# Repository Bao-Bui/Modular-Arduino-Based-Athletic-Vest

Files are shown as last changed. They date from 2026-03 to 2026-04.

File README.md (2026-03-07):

# Modular-Arduino-Based-Athletic-Vest

This fitness vest offers essential tracking—heart rate, steps, speed, and real-time goal feedback—combined with post-workout data storage via a local microSD card. Unlike traditional wearables, its open-enclosure design allows users to customize the device by adding Arduino-compatible sensors for advanced, personalized metrics.

### Materials:

* **Enclosed space (V5):** battery/top/bottom pieces; two side holes for nuts/bolts securing
* **Nuts and bolts (for enclosure fastening):** M3 x7, M4 x2
* **Haimont 10L running Vest**
* **Arduino + PCB “motherboard” assembly:** (PCB preserves Arduino pins through female headers)
* **SparkFun GPS module:** Chip Antenna, SAM-M10Q (Qwiic)
* **SparkFun OpenLog module:** (Qwiic)
* **MicroSD card:** (recommended: SanDisk 32GB Ultra, FAT32, 32GB)
* **MicroSD USB card reader**
* **MPU6050 Gyroscope/IMU**
* **JST cable harness:** (2.54 mm JST + 2.0 mm JST LCD end)
* **Qwiic wires**
* **ST7789 LCD screen:** + wrist case with Velcro
* **Power bank:** (INIU P41L-E2 class, 45W, 10,000 mAh)
* **Polar H10 chest strap + sensor:** (battery pre-installed)









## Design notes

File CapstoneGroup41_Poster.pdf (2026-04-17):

# Modular Athletic Vest

# Bao Bui, Oliver Escobar, Alexander Perez, Esei Haile Grand Canyon University

## Project Justification

- Most fitness wearables (Garmin, Fitbit, WHOOP) operate in closed ecosystems
- Users can only connect a limited set of approved sensors
- Advanced metrics (muscle activation, force, custom biomechanics) are not supported

## Project Description

The Modular Athletic Vest is an Arduino-based wearable designed to provide standard fitness tracking:
- Heart rate monitoring
- Step counting
- Speed tracking
- Real-time exercise feedback based on user goals
- Workout data storage on a microSD card

Unlike traditional wearables, the vest has a modular architecture, allowing users to integrate additional Arduino-compatible sensors to measure advanced physiological or biomechanical metrics.

Target Users
- Coaches analyzing athlete performance
- Competitive athletes needing advanced training metrics
- Tech-savvy fitness enthusiasts interested in custom hardware

## Design Process

The PCB layout includes connections for the Arduino R4, MPU6050 IMU, GPS module, OpenLog SD storage, and LCD interface. The design incorporates standardized mounting holes, optimized trace routing, and JST connectors for reliable communication and power distribution across the system (Fig. 1).

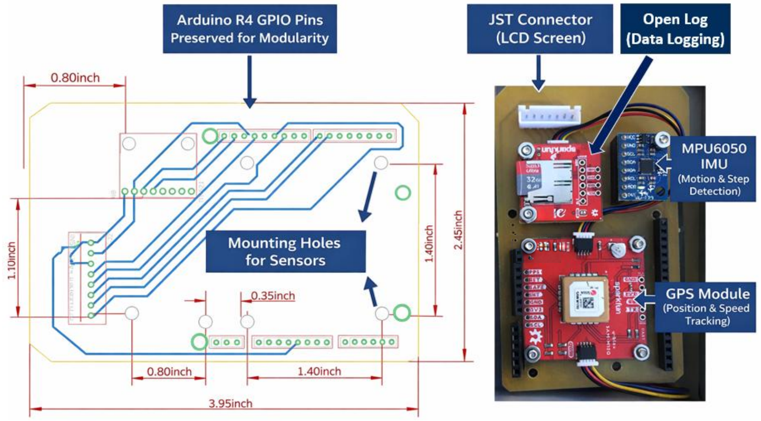
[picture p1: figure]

Figure 1. Custom PCB layout for an integrated sensor and microcontroller system.

System workflow from setup to output includes initialization, sensor integration, and data processing. Real-time inputs (heart rate, steps, and speed) are filtered and processed before being displayed on the LCD and stored for later analysis (Fig. 2).

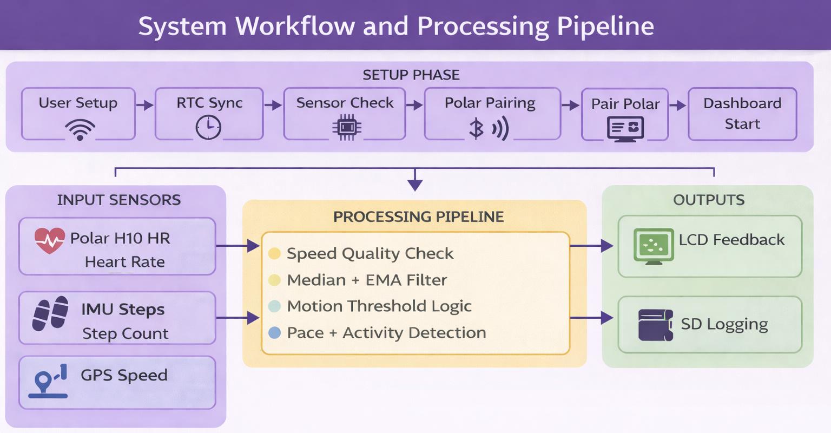
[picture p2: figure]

Figure 2. System workflow and real-time processing pipeline for the modular athletic vest.

A three-part enclosure houses the Arduino-PCB system and battery. The vest shows enclosure integration into the lower compartment with wiring for the LCD interface that was Velcro-mounted on a wrist case (Fig. 3).

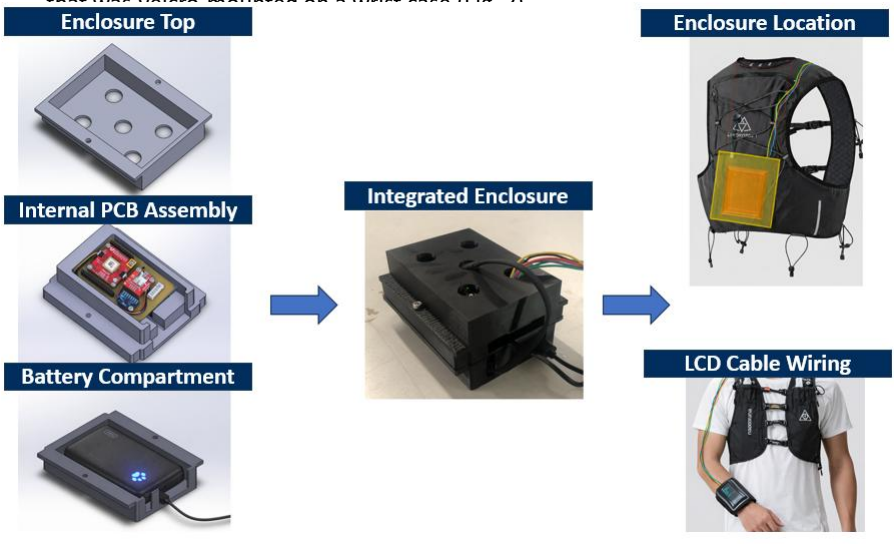
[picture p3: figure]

Figure 3. Enclosure design and integration into the wearable vest system.

## System Performance & Validation

The functional requirements assessment confirms that the modular athletic vest meets all key performance criteria, including accuracy in heart rate (100% specificity), step tracking (MAPE = 4.69%), speed tracking (MAPE = 8.86%), battery life, data storage, and enclosure design. Validation was guided by established standards such as IEC 62133-2:2017, IEC 60601-2-47:2012, ISO 924-210:2019, and ISO 12100, with additional benchmarking methods used where formal standards
were not available. Functional Requirement | Product Specification | Engineering Standards/ Alternative Tests | Result (Pass/Fail)
Long battery life | Runtime > 24 hours | IEC 62133-2:2017 | FAIL (23.5 hours)
Accurate heart rate detection | Specificity > 91% | IEC 60601-2-47:2012 | PASS (100%)
Accurate step tracking | MAPE < 20% (Mora-Gonzalez et al., 2022) | Manual step count comparison | PASS (4.69%)
Accurate speed tracking | MAPE < 10% (Alphin et al., 2020) | Radar gun comparison | PASS (8.86%)
Effective user feedback system | Rating ≥ 7/10 | ISO 9241-210:2019 | PASS (8.69)
User comfort | Rating ≥ 7/10 | ISO 9241-210:2019 | PASS (7.82)
Reliable data storage | Success rate ≥ 90% | Functional storage test | PASS (100%)
Modular enclosure | ≥ 2 holes ≥ 15 mm | Dimensional measurement | PASS
Secure enclosure locking | No failure under use | ISO 12100 | PASS
Sweat/water resistance | Hermeticity testing | IEC 60529 ISO 105-E04 | PENDING

## References

- International Electrotechnical Commission. (2017). Secondary cells and batteries containing alkaline or other non-acid electrolytes – Safety requirements for portable sealed secondary cells, and for batteries made from them, for use in portable applications – Part 2: Lithium systems (IEC 62133-2:2017).
- International Electrotechnical Commission. (2012). Medical electrical equipment—Part 2-47: Particular requirements for the basic safety and essential performance of ambulatory electrocardiographic systems (IEC 60601-2-47:2012).
- International Organization for Standardization. (2019). Ergonomics of human-system interaction—Part 210: Human-centred design for interactive systems (ISO 9241-210:2019).
- International Organization for Standardization. (2010). Safety of machinery—General principles for design—Risk assessment and risk reduction (ISO 12100).
- Alphin, K. L., Sisson, O. M., Hudgins, B. L., Noonan, C. D., & Bunn, J. A. (2020). Accuracy assessment of a GPS device for maximum sprint speed. International Journal of Exercise Science, 13(4), 273–280.
- Mora-Gonzalez, J., Gould, Z. R., Moore, C. C., Aguiar, E. J., Ducharme, S. W., Schuna, J. M., Barreira, T. V., Staudenmayer, J., McAvoy, C. R., Boikova, M., Miller, T. A., & Tudor-Locke, C. (2022). A catalog of validity indices for step counting wearable technologies during treadmill walking: The CADENCE-adults study. International Journal of Behavioral Nutrition and Physical Activity, 19(1), 117. https://doi.org/10.1186/s12966-022-01350-9

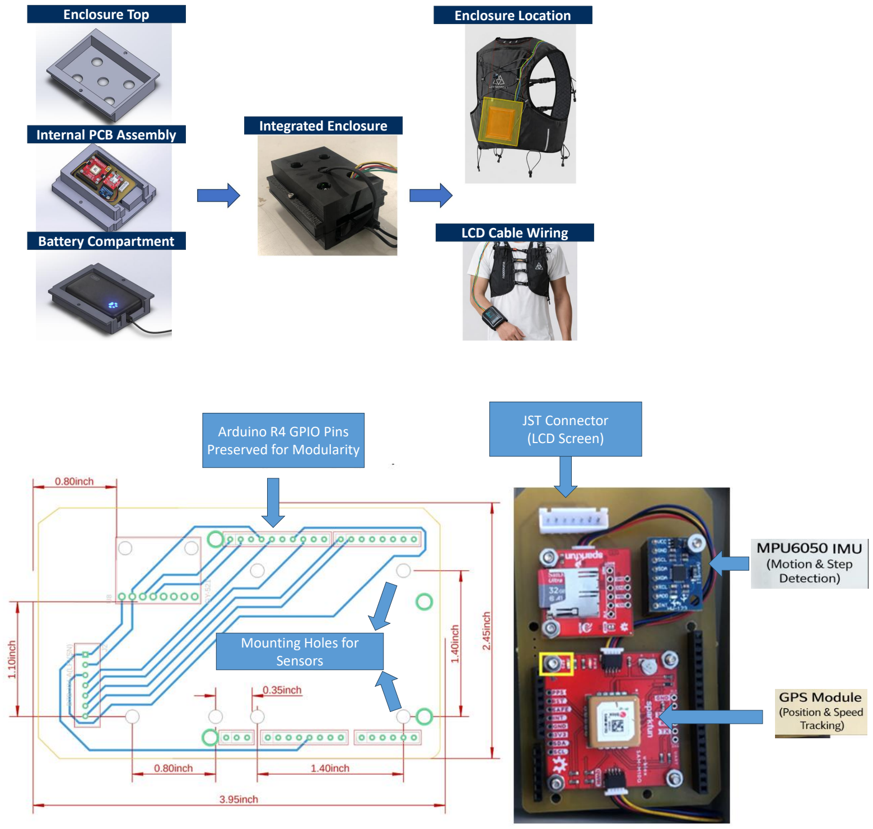
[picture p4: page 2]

JST Connector
(LCD Screen) Arduino R4 GPIO Pins Preserved for Modularity

Mounting Holes for
Sensors

Enclosure Top

Internal PCB Assembly

Battery Compartment

Integrated Enclosure

Enclosure Location

LCD Cable Wiring

Functional Requirement | Product Specification | Engineering Standards/ Alternative Tests | Result (Pass/Fail)
Long battery life | Runtime > 24 hours | IEC 62133-2:2017 | FAIL (23.5 hours)
Accurate heart rate detection | Specificity > 91% | IEC 60601-2-47:2012 | PASS (100%)
Accurate step tracking | MAPE < 20% (Mora-Gonzalez et al., 2022) | Manual step count comparison | PASS (4.69%)
Accurate speed tracking | MAPE < 10% (Alphin et al., 2020) | Radar gun comparison | PASS (8.86%)
Effective user feedback system | Rating ≥ 7/10 | ISO 9241-210:2019 | PASS (8.69)
User comfort | Rating ≥ 7/10 | ISO 9241-210:2019 | PASS (7.82)
Reliable data storage | Success rate ≥ 90% | Functional storage test | PASS (100%)
Modular enclosure | ≥ 2 holes ≥ 15 mm | Dimensional measurement | PASS
Secure enclosure locking | No failure under use | ISO 12100 | PASS
Sweat/water resistance | Hermeticity testing | IEC 60529 ISO 105-E04 | PENDING

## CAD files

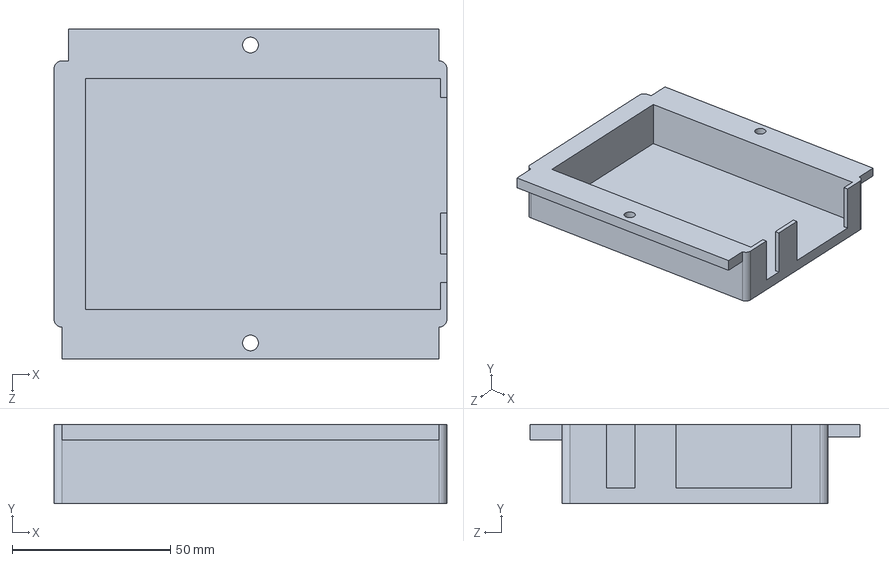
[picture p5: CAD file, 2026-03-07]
ArduinoEnclosureBattery_V2.SLDPRT
124.0 x 25.0 x 104.0 mm

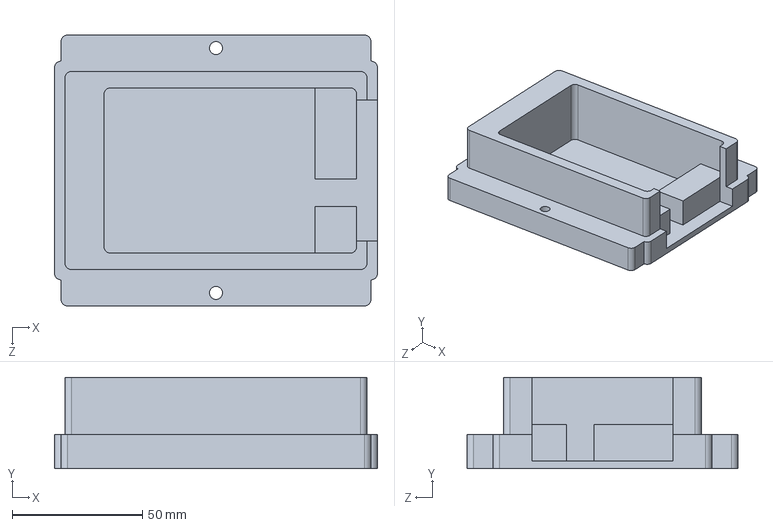
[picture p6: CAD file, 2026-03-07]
ArduinoEnclosureBottom_V2.SLDPRT
124.0 x 35.0 x 104.0 mm

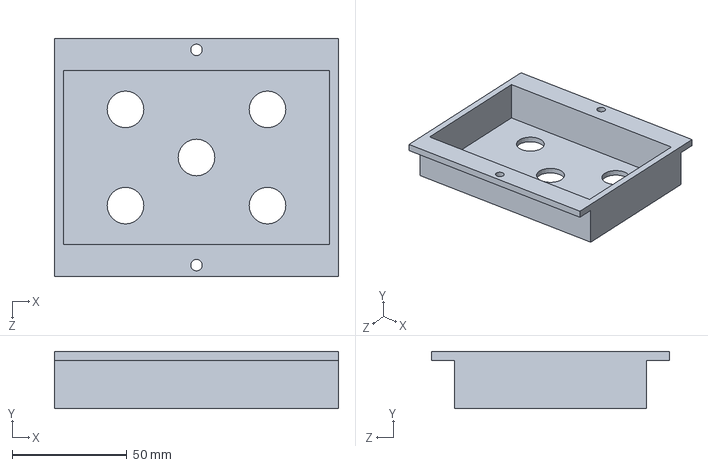
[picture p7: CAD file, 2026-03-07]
ArduinoEnclosureTop_V2.SLDPRT
124.0 x 25.0 x 104.0 mm

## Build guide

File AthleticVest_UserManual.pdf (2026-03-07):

# Arduino-Based Modular Athletic Vest

## User Manual & Research Guide

Prototype V5
Capstone Group 41, College of Engineering

Date: March 6, 2026

Table of Contents

## Contents

### 1. Intended Purpose and Use Limitations

The Arduino-Based Modular Athletic Vest is a wearable fitness-tracking system designed to record workout data such as heart rate, speed/pace (outdoor GPS), step count, and breathing estimates. It is intended for personal fitness training, experimentation, and Arduino-based sensor integration.

This device is not intended for medical purposes. It does not diagnose, treat, monitor, or prevent any disease or medical condition. All outputs should be treated as fitness-level estimates, not clinical measurements.

Use limitations and environment:
- Not rain/IP-rated: Do not use in rain, showers, or wet environments. The enclosure and electronics are not waterproof or IP-certified.
- Indoor use is limited: GPS typically will not lock indoors without a clear view of the sky, so speed/pace may be unavailable indoors.
- Normal sweat is acceptable. Wipe down after use.
- Avoid extreme temperatures. Storage/operation above 85°C is not recommended.

### 2. What’s Included (Package Contents)

Your kit includes the following components:
- Enclosed space (V5): battery/top/bottom pieces; two side holes for nuts/bolts securing
- Nuts and bolts (for enclosure fastening)
- M3 x7
- M4 x2
- Haimont 10L running Vest
- Arduino + PCB “motherboard” assembly (PCB preserves Arduino pins through female headers)
- SparkFun GPS module - Chip Antenna, SAM-M10Q (Qwiic)
- SparkFun OpenLog module (Qwiic)
- MicroSD card (recommended: SanDisk 32GB Ultra, FAT32, 32GB)
- MicroSD USB card reader
- MPU6050 Gyroscope/IMU
- JST cable harness (2.54 mm JST + 2.0 mm JST LCD end)
- Qwiic wires
- ST7789 LCD screen + wrist case with Velcro
- Power bank (INIU P41L-E2 class, 45W, 10,000 mAh)
- Polar H10 chest strap + sensor (battery pre-installed)

What the user must provide:
- Smartphone (for Vest_Setup Wi-Fi configuration)
- Laptop/computer (for viewing CSV files)

### 3. Device Description (How the System Works)

The vest system consists of a wearable platform (vest + wrist display) connected to a modular electronics enclosure that houses the Arduino and sensor/logging hardware. The vest records data during exercise and logs it to a microSD card as a CSV file for post-workout analysis. The system is intentionally modular so users can remove the Arduino/PCB assembly and attach additional Arduino-compatible sensors using available interfaces.

Major subsystems:
- Electronics enclosure: Holds Arduino + PCB, power connection, and sensor modules.
- Wrist display: LCD shows workout information and status.
- Sensor suite: GPS (outdoor speed/pace), IMU for steps/motion, Polar chest strap for HR and breathing estimate.
- Data logging: OpenLog + microSD stores workout CSV files for analysis.

### 4. Safety Information

4.1 Electrical and handling safety
This is an electronics-based fitness device. Use common electrical safety precautions. If anything smells hot, shuts off unexpectedly, or becomes unusually warm, immediately power down (unplug the power bank).
- Do not expose electronics to water (no rain, no submersion, no wet cleaning while electronics are installed).
- Do not operate with cracked housings, damaged insulation, or loose wiring.
- Do not modify wiring while the device is powered.

4.2 Environmental safety

- Not IP-rated: Do not use in rain or wet environments.
- Avoid dust-heavy or sandy environments that can contaminate connectors.
- Avoid extreme heat; do not leave in a hot vehicle.

4.3 Personal safety

- Route cables to avoid snagging during running.
- Wear the Polar chest strap comfortably; discontinue use if irritation occurs.
- If you have an implanted electronic device (e.g., pacemaker), use caution with wearable electronics and consult a professional if uncertain.

### 5. Setup and Assembly

5.1 Cable routing (if cable was removed)
The cable is usually already routed through the vest and wrist case. If it is removed accidentally, reroute it as follows:

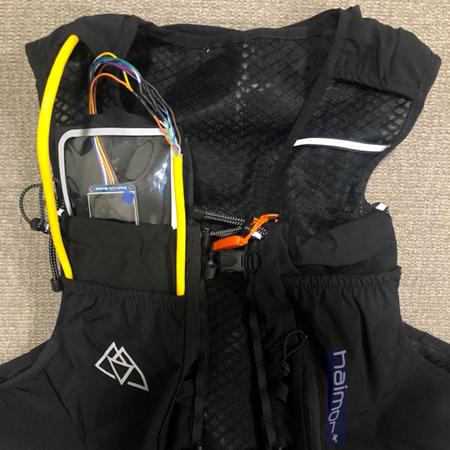
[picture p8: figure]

Figure 4. Cable routing through vest compartments (example layout).

1. Route the 2.54 mm JST end through the hole between the water compartment (largest compartment) and bottom compartment.
2. Route the 2.0 mm LCD JST end through the hole on the right shoulder.

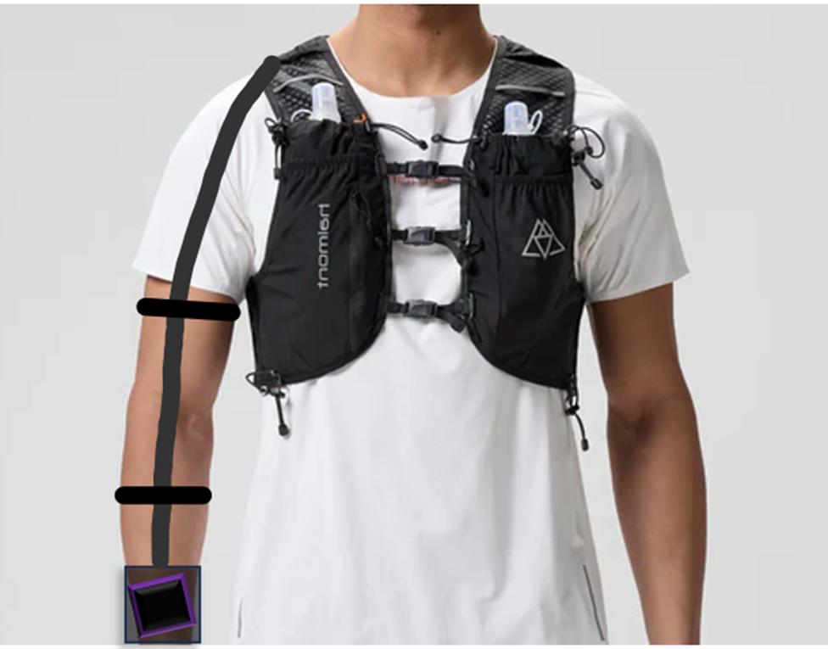
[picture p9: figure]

Figure 5. Recommended cable path from vest to wrist-mounted LCD (right arm).

3. Connect the 2.0 mm JST to the LCD and route the LCD/cable through the wrist case opening.
4. Secure the LCD in the wrist case using Velcro.
5. Tuck slack into the right chest pockets to keep the cable compact.

5.2 Installing electronics into enclosure
6. Route the 2.54 mm JST connector through the top-left hole of the enclosure cap.
7. Place the Arduino-PCB assembly in the enclosure with the Arduino USB-C port facing the wall-less side.
8. Plug the 2.54 mm JST connector into the PCB.
9. Insert the microSD card into the OpenLog until you feel/hear a secure “click.” (If it does not click, it may not log.)

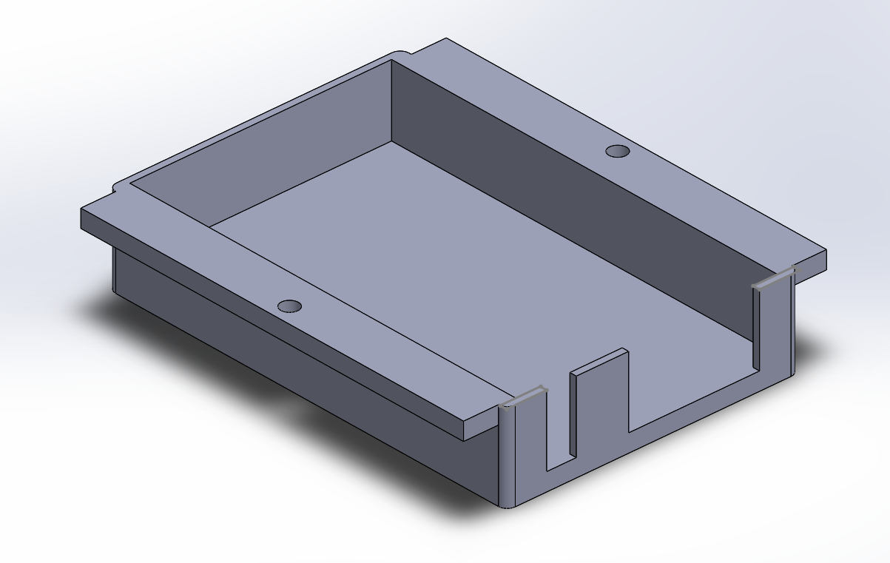
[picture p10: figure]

Figure 1. Enclosure V5 (top piece)

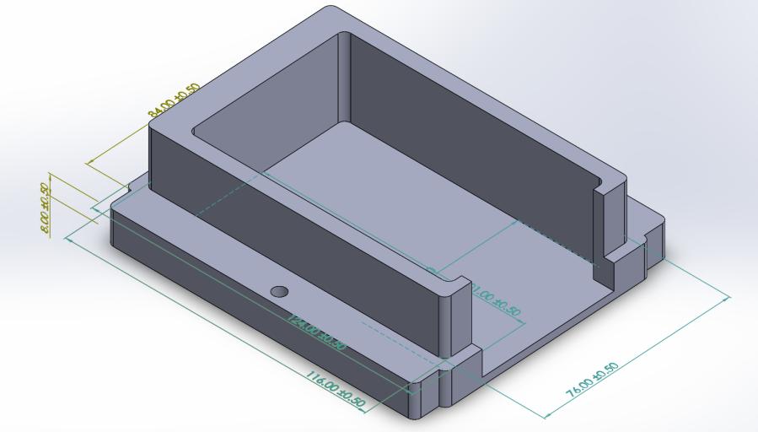
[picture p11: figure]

Figure 2. Enclosure V5 (assembled view with key dimensions)

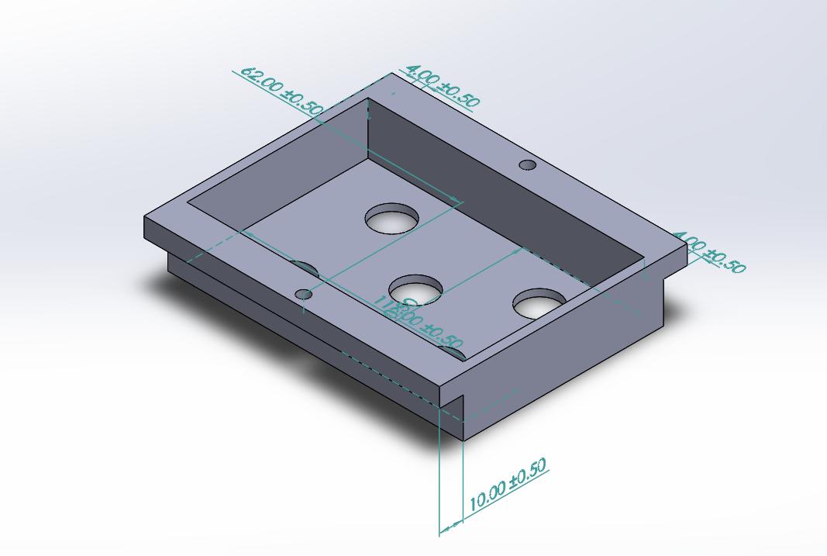
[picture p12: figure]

Figure 3. Enclosure V5 (bottom piece)

### 6. Operating Instructions (How to Start and Use)

6.1 Power on and GPS lock (outdoor)
Follow this sequence for reliable startup:
10. Power the Arduino via USB-C using the power bank.
11. For outdoor use, place the device with a clear view of the sky and wait for GPS lock. Normal wait time is 1–2 minutes.

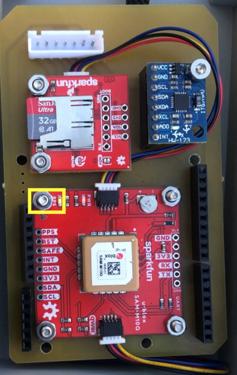
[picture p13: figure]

Figure 7. GPS module: PPS indicator (highlighted) blinks when satellites are locked.
12. Install the enclosure cap and secure it using nuts and bolts.
13. Place the enclosure in the bottom compartment and close the zipper.

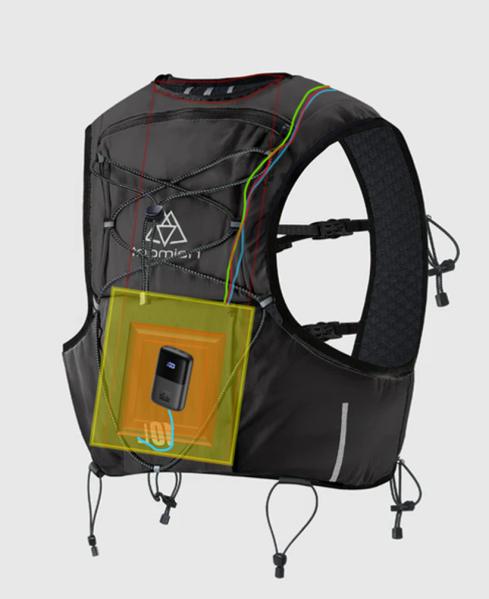
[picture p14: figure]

Figure 6. Electronics enclosure placement in the bottom compartment (example).

LED indicators: The power bank, GPS, IMU, and OpenLog will show indicator LEDs when powered, which confirms the system is receiving power.

6.2 Polar chest strap setup
Moisten the electrode area of the Polar chest strap and wear it snugly on the chest for reliable heart-rate detection. Detach the Polar sensor from the strap when finished to preserve battery life (typical sensor battery life is approximately 400 hours).

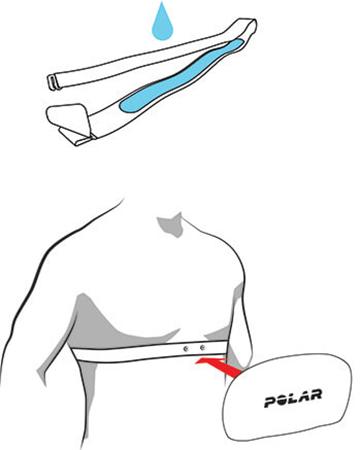
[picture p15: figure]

Figure 9. Polar chest strap setup: moisten electrode area and wear snugly on chest.

If the vest shows “???” for HR, the strap is not being detected. The most common cause is a dry strap. Moisten the strap and reseat it snugly. If the issue persists, power cycle the device (unplug the power bank, then restart).

6.3 Start workout configuration (phone)
14. Put the vest on.
15. Put the wrist case on the right arm (left arm may invert display text).
16. On your phone, connect to the Wi‑Fi network “Vest_Setup”.
17. Navigate to 192.168.4.1 in your browser to configure settings and goals.

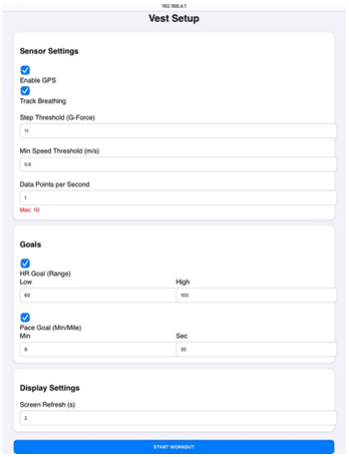
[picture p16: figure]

Figure 8. Vest_Setup configuration page (GPS can be disabled for indoor workouts).

18. Tap Start Workout to begin pairing and logging. You may begin exercising after pairing completes.

### 7. Settings and Recommendations (User-Tunable)

7.1 GPS mode

- Indoor: Turn OFF GPS in setup (speed/pace will not be reliable indoors).
- Outdoor: Turn ON GPS to track speed/pace (requires clear view of sky).

7.2 Parameters
Step Threshold (G‑force): magnitude above which a step is counted. Recommended values:
- Walking: ~11G
- Running: ~13G

Min Speed Threshold (m/s): filters false non-zero speed when stationary. Recommended range: 0.6–0.8 m/s. Higher values reduce stationary drift but may be less sensitive to slow walking; lower values are more sensitive but may show more low-speed noise.

Data Points per Second: how often data is saved to microSD. Users may select 1–10 points/sec. Higher rates increase file size and may reduce battery life slightly.

7.3 Goals

- HR goal: defines the target HR range used for status feedback.
- Pace goal: defines the outdoor pace threshold used for “speed up/on pace” feedback.

### 8. Data Logging and File Export

8.1 How data is stored
Workout data is saved to the microSD card as a CSV file. To read the data, remove the microSD card and use the included USB reader on a laptop.

File naming format: MMDDHHMM (example: 01242003 = Jan 24 at 20:03).

8.2 CSV columns (what they mean)

- MILLIS: Arduino elapsed time (ms) since startup
- HR: heart rate (bpm)
- PACE_MIN / PACE_SEC: outdoor pace in min/mile (when GPS is enabled and locked)
- SPEED_MS: speed in meters/second
- ACTIVITY: STOP / WALK / JOG / RUN / SPRINT classification based on filtered speed
- BREATHS: estimated breath count (derived from RR intervals when available)
- STEPS: step count from IMU thresholding

Excel note: CSV files may auto-format fields. If something looks wrong, import the CSV and set columns to “Text” or “Number” as appropriate.

### 9. Shutdown Procedure (How to Turn Off and Disassemble)

Follow this shutdown order to preserve data and prevent corruption:
19. Remove the LCD wrist case and tuck slack into the right chest pocket if desired.
20. Remove the vest.
21. Detach the Polar sensor from the strap to turn it off and preserve battery life.
22. Open bottom compartment and remove the enclosure.
23. Remove nuts/bolts and open the enclosure.

24. Unplug the power bank from the Arduino to power off.
25. Remove the microSD card from the OpenLog.
26. Insert microSD into the USB reader and view CSV files on a laptop.

### 10. Maintenance, Cleaning, and Storage

10.1 Cleaning
If electronics are installed: clean by wiping only.
- Use a damp cloth.
- Do not submerge.
- Do not rinse under running water.
- Do not use harsh solvents.

Machine washing: The vest fabric may be machine-washed only if ALL electronics are removed, including the enclosure with electronics, the Arduino + PCB assembly (including OpenLog and IMU mounted to it), the LCD/wrist module, the power bank, and all current-carrying cables.

10.2 Storage

- Store dry at room temperature.
- Keep water away from the microSD card and exposed electronics.
- Avoid extreme heat; do not store above 85°C.

### 11. Modularity and Expansion (Arduino-Compatible Sensors)

The vest is designed to support sensor expansion. Users may remove the Arduino + PCB assembly from the enclosure to attach additional Arduino-compatible sensors. The PCB preserves Arduino pin access via female headers, allowing common interfaces including I2C, UART, SPI, and ADC.
Important safety limits for expansion:
- Do not connect motors, heaters, solenoids, or other high-power loads directly to Arduino pins.
- Keep external sensor loads light. Conservative rule: <= 20 mA per GPIO pin.
- Use external drivers for loads beyond small sensors (not included).
- Verify correct voltage levels for your sensors (3.3V vs 5V) and do not short power rails.

### 12. Troubleshooting and Common Errors

12.1 No GPS lock / speed stuck at 0 (outdoor)
Likely cause: no clear view of the sky. Fix: move to an open outdoor area, wait 1–2 minutes for lock, and if still not locked, unplug and replug the power bank (power cycle) and retry with clear sky view.

12.2 Polar won’t pair / HR shows “???” / unreasonable HR
Likely cause: strap electrodes are dry or strap not snug. Fix: moisten electrode areas and reseat strap firmly. If HR still shows “???”, unplug and replug the power bank and repeat startup.

12.3 LCD screen is blank
Likely cause: JST connection loosened. Fix: check both JST connections are fully seated. Unplug and replug the power bank to restart.

12.4 SD not logging / missing CSV files
Likely causes: SD not inserted, or not fully seated. Fix: confirm microSD is inserted into OpenLog until you hear/feel a “click.” Confirm the microSD is the provided/recommended type (SanDisk 32GB Ultra FAT32). Restart the system after reseating the SD card.

### 13. Quick Start Checklist

- Insert microSD until it clicks.
- Connect JST harness to PCB and LCD.
- Plug in power bank (LEDs indicate powered sensors).
- Outdoor: wait for GPS PPS blink (1–2 min) before closing enclosure.
- Put on chest strap (moisten electrodes).
- Phone: connect to Vest_Setup -> go to 192.168.4.1 -> set parameters -> Start Workout.
- After workout: unplug power bank -> remove microSD -> read CSV on laptop.

### 14. Use Example

14,1 Cable routing

Note: Cable should already be routed into vest and wrist case, but below is step-by-step guide for users to route cable back into the vest and wrist case, should they accidentally take it out.

1. Route the 2.54-mm JST end of the cable through the hole between the water compartment (i.e., largest compartment) and bottom compartment

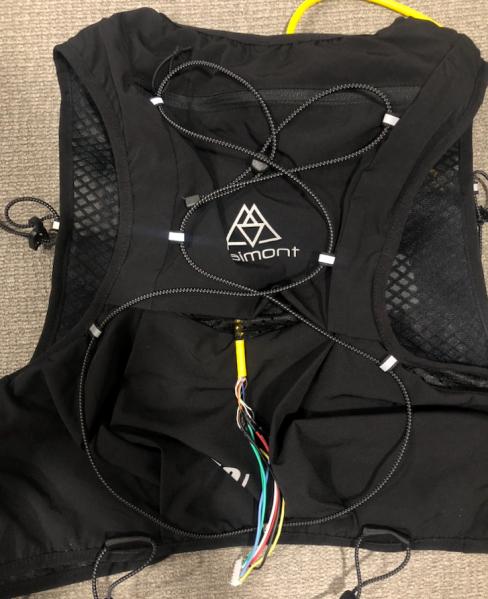
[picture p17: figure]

2. Route the 2-mm LCD JST end of the cable through the hole on the right shoulder.

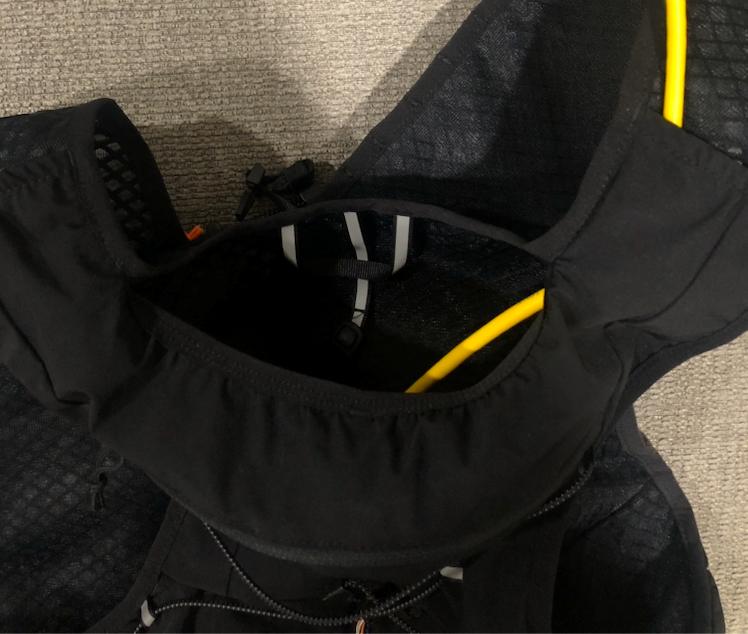
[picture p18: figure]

3. Connect 2-mm JST to the LCD and route the LCD and cable through the hole on the wrist case.
4. Secure the LCD in the wrist case with Velcro.

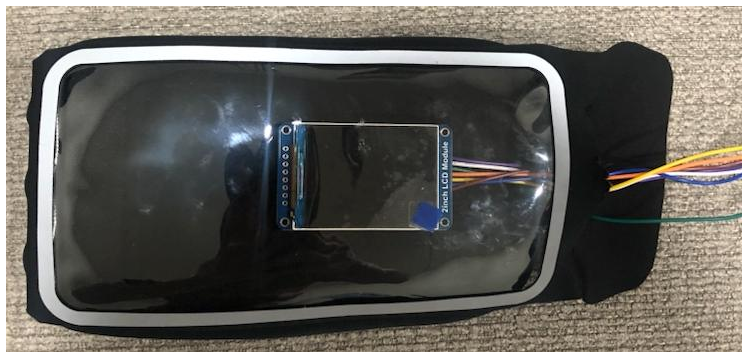
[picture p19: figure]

5. To keep cable compact, the LCD wrist case and cable slack may be tucked into the right chest pockets on the vest.

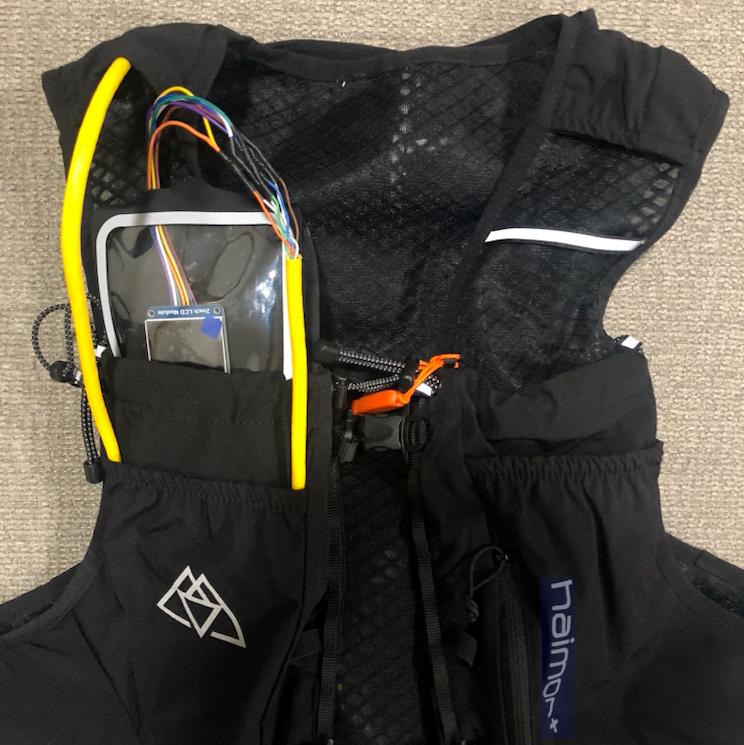
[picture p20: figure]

14.2 Vest setup

1. Route the 2.54-mm JST connector through the TOP LEFT hole of the enclosure cap.

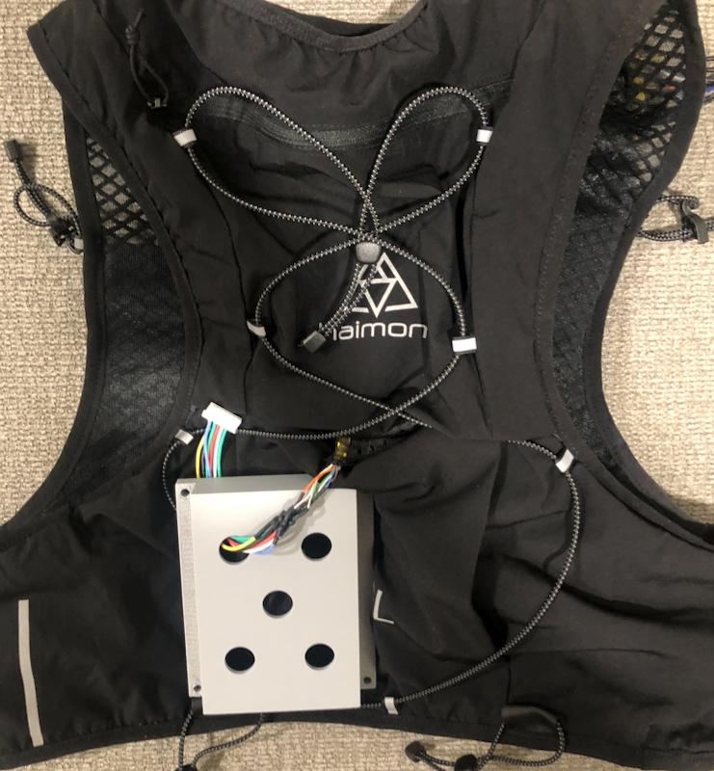
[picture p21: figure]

2. Put Arduino-PCB complex in the enclosure, with the USB-C port on the Arduino facing the wall-less side.
3. Plug the 2.54-mm JST connector to the PCB.
4. Power on the Arduino via the USB-C port with the power bank.

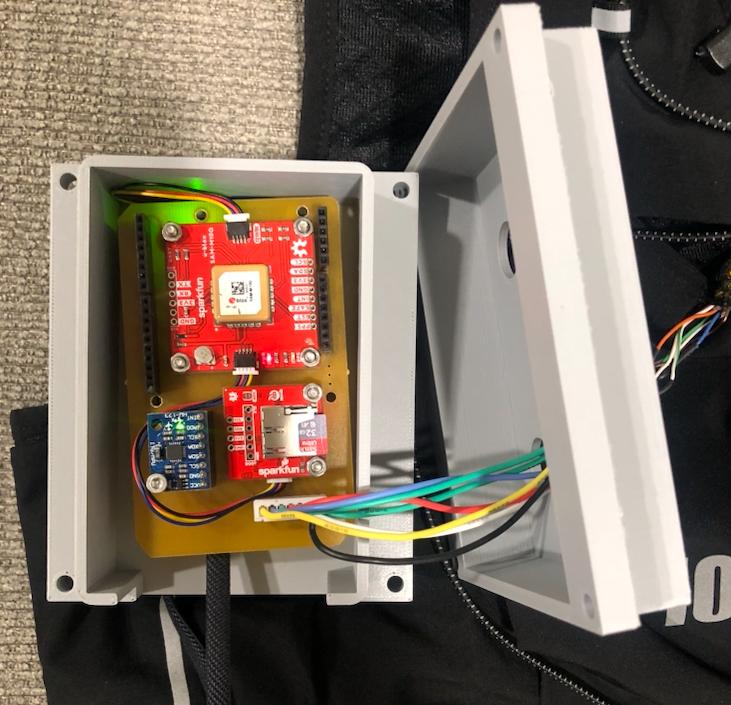
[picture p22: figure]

5. If used OUTDOORS [OMITTED FOR INDOOR USE], give the SparkFun SAM-M10Q GPS a clear view of the sky. Make sure that the PPS light thereon is blinking, which signifies that the sensor successfully locks with satellite for location and speed tracking before closing the enclosure.

6. Put the enclosure cap on and secure with nuts and bolts.

7. Put the enclosure in the bottom compartment and close the zipper.

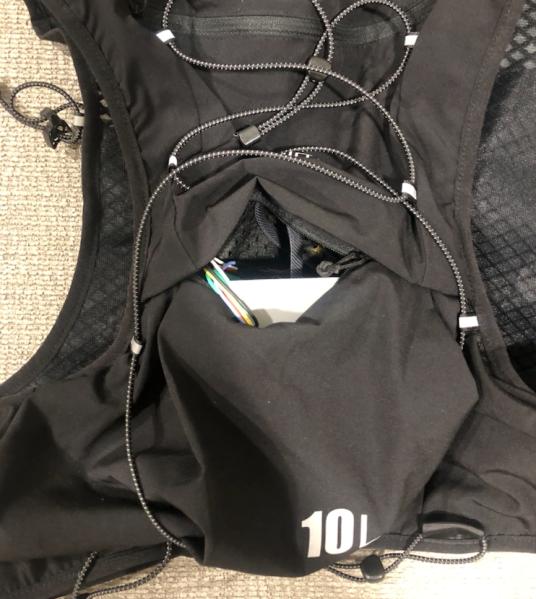
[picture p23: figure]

8. Moisten the electrode area of the Polar chest strap and put it on the chest. The sensor is ON as long as it is attached to the strap. To turn the the sensor OFF, it needs to be detached.

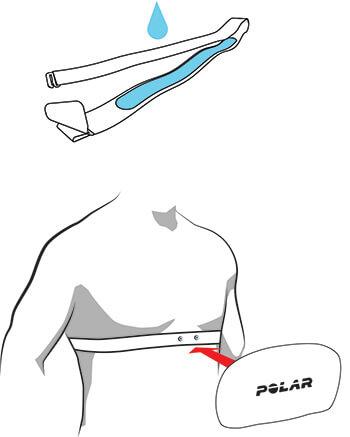
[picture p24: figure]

9. Put the vest on.

10. Put the wrist case on the right arm [NOTE: Using the left arm with result in inverted texts]
11. On your phone, connect to the Wi-Fi “Vest_Setup”

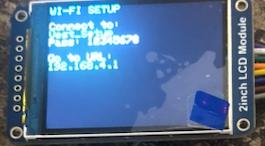
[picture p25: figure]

12. Go to 192.168.4.1 local server on your browser to set up sensor parameters and goals before starting exercise.
a. TURN OFF GPS for INDOOR USE. TURN ON GPS for OUTDOOR USE to track speed.
b. Parameters:
i. Step Threshold: G-Force above which a step is counted. RECOMMEND 11G for walking and 13G for running
ii. Min Speed Threshold:
1. Eliminate errors of positive speed when user is stationary.
2. Higher threshold = More effective error filter, but less sensitive to walking speed
3. Lower threshold = More positive speed noise at low speed and stationary state, but more sensitive to walking speed
4. RECOMMEND threshold of 0.6-0.8 m/s
iii. Data Points per Second: Rate at which data is saved into the microSD card storage
c. Goals:
i. HR goal: The range outside of which HR is considered abnormal
ii. Pace goal: Running pace, slower than which is considered failing
d. Display settings: How often LCD screen is refreshed with new measurements

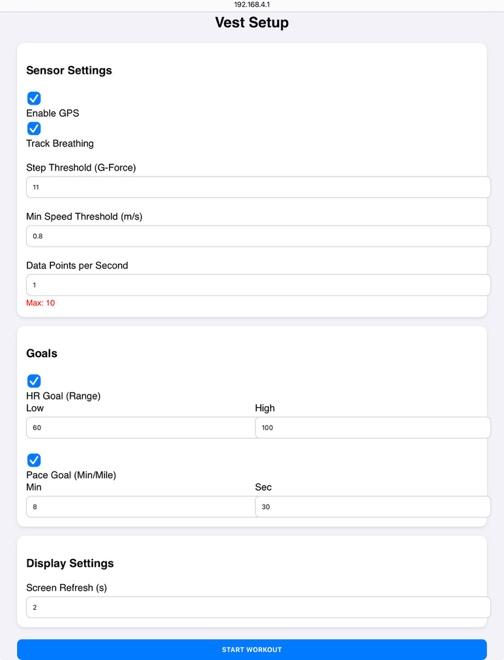
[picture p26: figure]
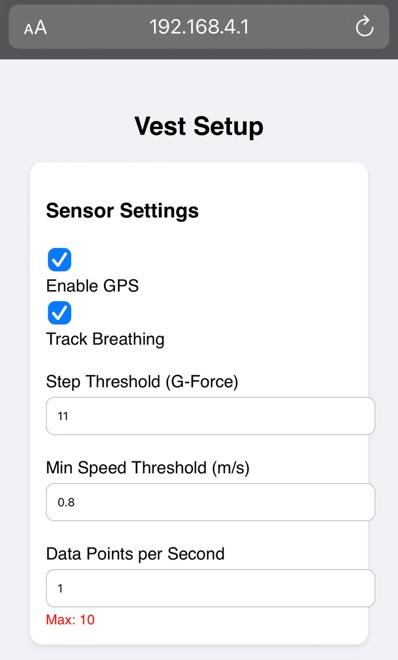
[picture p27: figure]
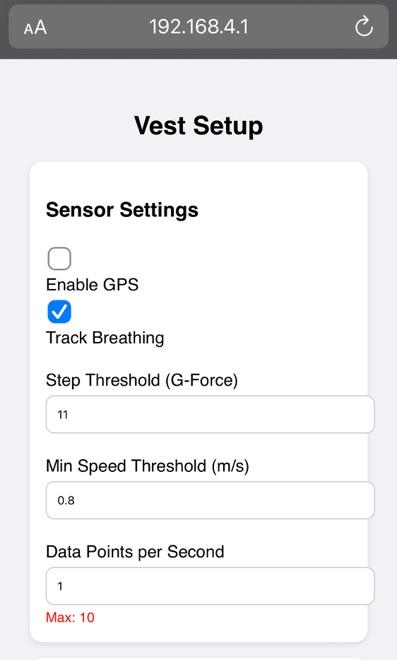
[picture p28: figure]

13. Hit “Start Workout” on the local server to start pairing sensors. You can start exercise when pairing is complete!

14.3 Disassemble vest

1. Take off the LCD wrist case. To keep cable compact, the LCD wrist case and cable slack may be tucked into the right chest pockets on the vest.
2. Take off the vest.
3. Detach the Polar sensor from the chest strap to turn it off and save sensor battery.
4. Open the bottom compartment and take the enclosure out.

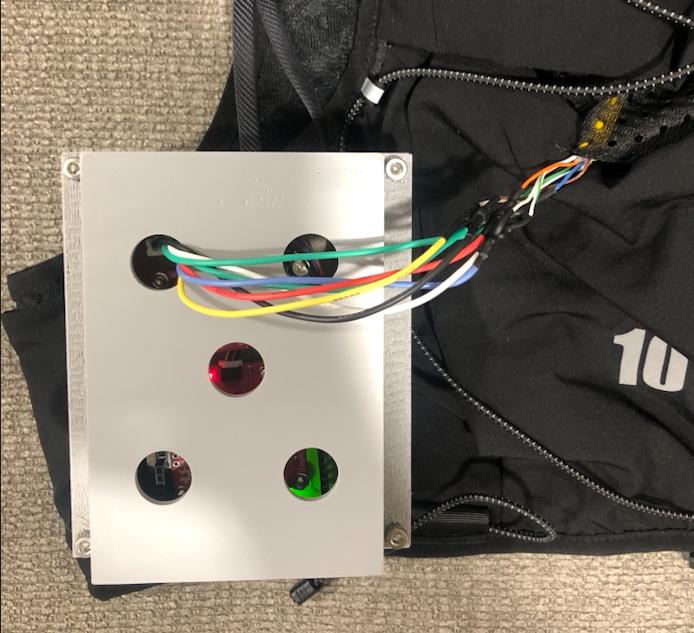
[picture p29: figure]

5. Take off the nuts and bolts and open the enclosure.
6. Unplug the power bank from the Arduino to power off.
7. Take the microSD card out from the SparkFun OpenLog.
8. The microSD card may be read on a laptop using USB reader, allowing users to view their exercise data in CSV files.

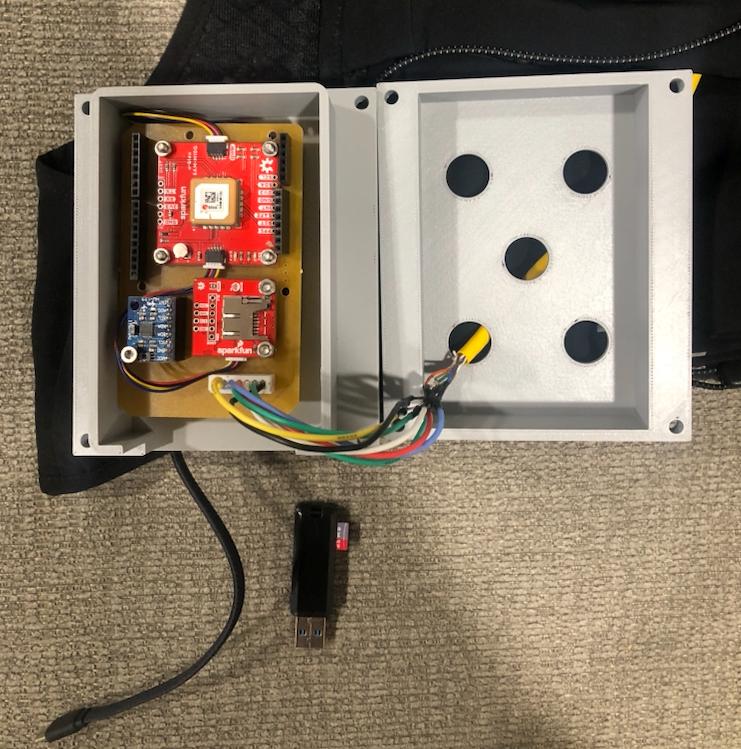
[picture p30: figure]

9. The naming format is MMDDHHMM (e.g., 01242003 = Jan 24, 20:03)

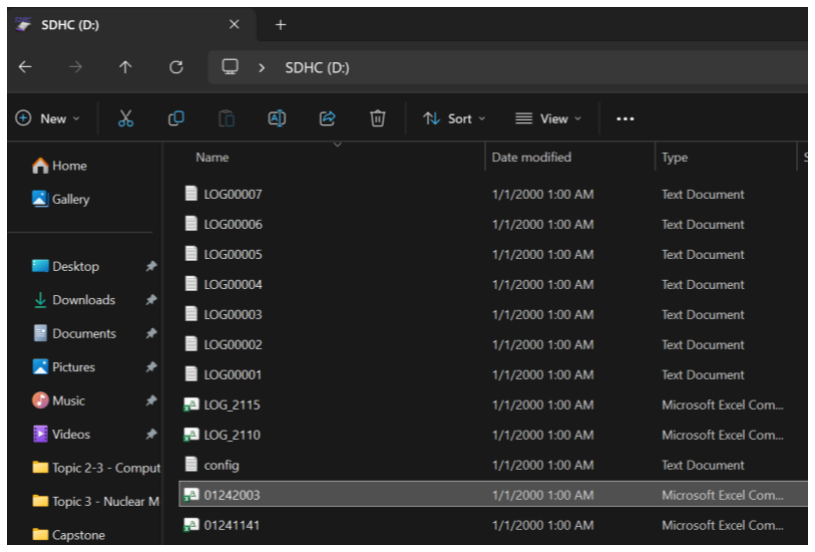
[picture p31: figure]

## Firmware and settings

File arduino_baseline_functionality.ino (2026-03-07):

/*
   CAPSTONE VEST - FINAL FIRMWARE V12 (Activity Logging + Speed Smoothing)

   Hardware:
   - Arduino Uno R4 WiFi
   - SparkFun Qwiic OpenLog (Wire1)
   - SparkFun GPS (Wire1)
   - MPU6050 (Wire - Standard)
   - Adafruit ST7789 (SPI)

   V12 changes:
   - Speed smoothing: Median-of-5 + EMA + hysteresis + decay-to-zero
   - CSV: Add ACTIVITY column (STOP/WALK/JOG/RUN/SPRINT)
   - Speed decimals: LCD shows 2 dp, CSV logs 3 dp
   - Pace: corrected to Min/Mile
   - RTC month fix: RTC.getMonth() is typically 0-based -> +1 for logging/filename
*/

#include <Wire.h>
#include <SPI.h>
#include <Adafruit_GFX.h>
#include <Adafruit_ST7789.h>
#include <ArduinoBLE.h>
#include <SparkFun_u-blox_GNSS_v3.h>
#include <Adafruit_MPU6050.h>
#include <Adafruit_Sensor.h>
#include <WiFiS3.h>
#include <RTC.h>
#include "SparkFun_Qwiic_OpenLog_Arduino_Library.h"

// ---------------- LCD CONFIGURATION ----------------
#define TFT_CS    10
#define TFT_DC     7
#define TFT_RST    6
#define ST77XX_DARKGREY 0x4208
#define ST77XX_ORANGE   0xFA60
Adafruit_ST7789 tft = Adafruit_ST7789(TFT_CS, TFT_DC, TFT_RST);

// ---------------- HARDWARE OBJECTS ----------------
Adafruit_MPU6050 mpu;
SFE_UBLOX_GNSS myGNSS;
WiFiServer server(80);
OpenLog myLog;

// ---------------- BLE VARIABLES ----------------
const char* polarServiceUuid = "180D";
const char* polarCharUuid = "2A37";
BLEDevice polarDevice;
BLECharacteristic hrChar;
bool polarConnected = false;

// ================================================================
// SETTINGS (User-configurable via WiFi page)
// ================================================================
float stepThreshold = 11.0;
float minSpeedThreshold = 0.8;   // used as start-moving threshold (m/s)
int hrLow = 60, hrHigh = 100;
int goalPaceMin = 8, goalPaceSec = 30;
int lcdFreqMs = 2000;
int logFreqMs = 1000;

bool setHrGoal = true;
bool setPaceGoal = true;
bool useGPS = true;
bool useBreathing = true;
bool isConfigured = false;

// ================================================================
// SPEED PROCESSING TUNING
// ================================================================
// If your GNSS library supports getFixType/getSIV, keep ON.
// If compile errors happen, set to 0.
#define USE_GNSS_QUALITY_GATING 1

static const uint8_t SPEED_MEDIAN_N = 5;
static const float   SPEED_EMA_ALPHA = 0.25f;     // lower = smoother (more lag)
static const float   HYSTERESIS_DELTA = 0.20f;    // stopThresh = startThresh - delta
static const float   STOP_DECAY_MULT = 0.85f;     // decay when stopped
static const float   DISPLAY_DEADBAND = 0.05f;    // clamp tiny values to 0
static const float   MAX_REASONABLE_SPEED = 15.0f; // m/s safety cap

static const uint32_t SPEED_UPDATE_MS = 200;      // display/log speed refresh cadence
static const uint32_t GNSS_STALE_MS   = 2000;     // if no good GNSS for this long, decay harder

// ================================================================
// DATA
// ================================================================
int currentHR = 0;
int stepCount = 0;
unsigned long lastStepTime = 0;
bool isStepHigh = false;
const int STEP_DELAY_MS = 300;

long totalBreaths = 0;
float rrHistory[3] = {0, 0, 0};

// ---------------- SPEED STATE ----------------
float displaySpeed = 0.0f;              // m/s (filtered, user-facing)
int displayPaceMin = 0, displayPaceSec = 0;

static float speedBuf[SPEED_MEDIAN_N];
static uint8_t speedBufCount = 0;
static uint8_t speedBufIdx = 0;

static float speedEma = 0.0f;
static bool  moving = false;

static unsigned long lastSpeedUpdateMillis = 0;
static unsigned long lastGoodGnssMillis = 0;

// ---------------- LOGGING ----------------
String logFileName = "LOG.CSV";
unsigned long arduinoStartMillis = 0;
unsigned long lastLogMillis = 0;
unsigned long lastLcdMillis = 0;

// ================================================================
// PROTOTYPES
// ================================================================
void startWiFiConfig();
void parseConfig(String req);
String getParam(String req, String tag);
void sendSetupPage(WiFiClient c);
void sendSuccessPage(WiFiClient c);

void drawDashboardLayout();
void updateDashboard();
void processPolarData();
void runStepCounter();
void pollGPS();
void logData(unsigned long ms);

// Speed helpers
float medianOfBuffer(const float* buf, uint8_t count);
void  pushSpeedSample(float s);
void  updateSpeedFromPipeline(unsigned long nowMillis, bool gnssGood);

// Activity classification
const char* classifyActivity(float speedMS);

// ================================================================
// SETUP
// ================================================================
void setup() {
  tft.init(240, 320);
  tft.setRotation(1);
  tft.fillScreen(ST77XX_BLACK);

  RTC.begin();

  // 1) WiFi config & RTC sync
  startWiFiConfig();

  // 2) Switch radio
  tft.fillScreen(ST77XX_BLACK);
  tft.setCursor(20, 100); tft.setTextColor(ST77XX_YELLOW); tft.setTextSize(3);
  tft.println("SWITCHING");
  tft.setCursor(20, 140); tft.println("RADIO...");

  WiFi.disconnect();
  WiFi.end();
  delay(3000);

  // 3) Sensor checks
  tft.fillScreen(ST77XX_BLACK);
  tft.setTextSize(2);

  Wire.begin();
  Wire1.begin();

  // GPS
  tft.setCursor(10, 10); tft.setTextColor(ST77XX_WHITE); tft.print("GPS: ");
  if (useGPS) {
    while (!myGNSS.begin(Wire1)) {
      tft.fillRect(60, 10, 140, 20, ST77XX_BLACK);
      tft.setCursor(60, 10); tft.setTextColor(ST77XX_RED); tft.print("RETRY...");
      delay(1000);
    }
    tft.fillRect(60, 10, 140, 20, ST77XX_BLACK);
    tft.setCursor(60, 10); tft.setTextColor(ST77XX_GREEN); tft.println("OK");
    myGNSS.setI2COutput(COM_TYPE_UBX);
    myGNSS.setNavigationFrequency(5); // 5 Hz
  } else {
    tft.setTextColor(ST77XX_ORANGE); tft.println("DISABLED");
  }

  // IMU
  tft.setCursor(10, 40); tft.setTextColor(ST77XX_WHITE); tft.print("IMU: ");
  while (!mpu.begin()) {
    tft.fillRect(60, 40, 140, 20, ST77XX_BLACK);
    tft.setCursor(60, 40); tft.setTextColor(ST77XX_RED); tft.print("RETRY...");
    delay(1000);
  }
  tft.fillRect(60, 40, 140, 20, ST77XX_BLACK);
  tft.setCursor(60, 40); tft.setTextColor(ST77XX_GREEN); tft.println("OK");

  // LOG
  tft.setCursor(10, 70); tft.setTextColor(ST77XX_WHITE); tft.print("LOG: ");
  if (!myLog.begin(QOL_DEFAULT_ADDRESS, Wire1)) {
    tft.setTextColor(ST77XX_RED); tft.println("FAIL");
  } else {
    tft.setTextColor(ST77XX_GREEN); tft.println("OK");

    RTCTime now;
    RTC.getTime(now);

    // FIX: Month is typically 0-based with RTC.h -> add +1 for human-readable
    int month1 = (int)now.getMonth() + 1;

    char fileNameBuff[13];
    sprintf(fileNameBuff, "%02d%02d%02d%02d.CSV",
            month1, now.getDayOfMonth(), now.getHour(), now.getMinutes());
    logFileName = String(fileNameBuff);

    myLog.append(logFileName);

    myLog.print("RTC_START_DATE,");
    myLog.print(String(now.getDayOfMonth()) + "/" + String(month1) + "/" + String(now.getYear()));
    myLog.println();

    myLog.print("RTC_START_TIME,");
    myLog.print(String(now.getHour()) + ":" + String(now.getMinutes()) + ":" + String(now.getSeconds()));
    myLog.println();

    arduinoStartMillis = millis();
    myLog.print("ARDUINO_START_MILLIS,"); myLog.println(arduinoStartMillis);

    // NEW: ACTIVITY column
    myLog.println("MILLIS,HR,PACE_MIN,PACE_SEC,SPEED_MS,ACTIVITY,BREATHS,STEPS");
  }

  // BLE
  tft.setCursor(10, 100); tft.setTextColor(ST77XX_WHITE); tft.print("BLE: ");
  if (!BLE.begin()) {
    tft.setTextColor(ST77XX_RED); tft.println("FAIL!");
    while (1);
  }
  tft.setTextColor(ST77XX_GREEN); tft.println("OK");

  // 4) Polar pairing
  tft.setCursor(10, 140); tft.setTextColor(ST77XX_BLUE); tft.println("Scan Polar H10...");

  BLE.scanForUuid(polarServiceUuid);
  while (!polarConnected) {
    BLEDevice peripheral = BLE.available();
    if (peripheral) {
      BLE.stopScan();
      if (peripheral.connect()) {
        if (peripheral.discoverAttributes()) {
          hrChar = peripheral.characteristic(polarCharUuid);
          if (hrChar && hrChar.subscribe()) {
            polarConnected = true;
            polarDevice = peripheral;

            tft.fillRect(10, 140, 240, 30, ST77XX_BLACK);
            tft.setCursor(10, 140); tft.setTextColor(ST77XX_GREEN); tft.println("Polar Paired!");
            delay(1000);
          }
        }
      }
      if (!polarConnected) BLE.scanForUuid(polarServiceUuid);
    }
  }

  drawDashboardLayout();
}

// ================================================================
// LOOP
// ================================================================
void loop() {
  unsigned long currentMillis = millis();

  if (polarConnected) {
    BLE.poll();
    if (hrChar.valueUpdated()) processPolarData();
    if (!polarDevice.connected()) polarConnected = false;
  }

  runStepCounter();
  if (useGPS) pollGPS();

  if (currentMillis - lastLogMillis >= (unsigned long)logFreqMs) {
    logData(currentMillis);
    lastLogMillis = currentMillis;
  }

  if (currentMillis - lastLcdMillis >= (unsigned long)lcdFreqMs) {
    updateDashboard();
    lastLcdMillis = currentMillis;
  }
}

// ================================================================
// LOGGING (CSV)
// ================================================================
void logData(unsigned long ms) {
  String dataRow = String(ms) + ",";
  dataRow += String(currentHR) + ",";

  if (useGPS) {
    // Pace (Min/Mile)
    dataRow += String(displayPaceMin) + ",";
    dataRow += String(displayPaceSec) + ",";

    // Speed: log 3 decimals (matches mm/s resolution best)
    dataRow += String(displaySpeed, 3) + ",";

    // Activity label from filtered speed
    dataRow += String(classifyActivity(displaySpeed)) + ",";
  } else {
    dataRow += "0,0,0,NA,";
  }

  dataRow += String(totalBreaths) + ",";
  dataRow += String(stepCount);

  myLog.append(logFileName);
  myLog.println(dataRow);
}

// ================================================================
// ACTIVITY CLASSIFICATION
// ================================================================
const char* classifyActivity(float speedMS) {
  // You can tune these cutoffs any time without touching the filter pipeline.
  // Based on your ranges screenshot (m/s):
  // Jogging: 1.8–4.9
  // Running: 4.5–6.5 (we use 4.5+)
  // Sprinting: > 7.0
  // Walking: below 1.8 but above "stopped"
  const float STOP_CUTOFF = 0.50f; // treat near-zero as STOP for analysis

  if (speedMS < STOP_CUTOFF) return "STOP";
  if (speedMS < 1.80f)       return "WALK";
  if (speedMS < 4.50f)       return "JOG";
  if (speedMS < 7.00f)       return "RUN";
  return "SPRINT";
}

// ================================================================
// WIFI SETUP / CONFIG
// ================================================================
void startWiFiConfig() {
  WiFi.config(IPAddress(192, 168, 4, 1));
  WiFi.beginAP("Vest_Setup", "12345678");
  server.begin();

  tft.setTextColor(ST77XX_CYAN); tft.setTextSize(2);
  tft.println("WI-FI SETUP");
  tft.setTextColor(ST77XX_WHITE);
  tft.println("\nConnect to:");
  tft.setTextColor(ST77XX_GREEN); tft.println("Vest_Setup");
  tft.setTextColor(ST77XX_WHITE);
  tft.println("Pass: 12345678");
  tft.println("\nGo to URL:");
  tft.setTextColor(ST77XX_GREEN); tft.println("192.168.4.1");

  while (!isConfigured) {
    WiFiClient client = server.available();
    if (client) {
      String request = "";
      while (client.connected()) {
        if (client.available()) {
          char c = client.read();
          request += c;
          if (c == '\n') {
            if (request.indexOf("GET /START") >= 0) {
              parseConfig(request);
              isConfigured = true;
              sendSuccessPage(client);
              break;
            } else {
              sendSetupPage(client);
              break;
            }
          }
        }
      }
      client.stop();
    }
  }
}

void parseConfig(String req) {
  // set RTC from browser epoch (seconds)
  int tIndex = req.indexOf("time=");
  if (tIndex != -1) {
    int endT = req.indexOf("&", tIndex);
    if (endT == -1) endT = req.indexOf(" ", tIndex);
    String tStr = req.substring(tIndex + 5, endT);
    unsigned long epoch = strtoul(tStr.c_str(), NULL, 10);
    RTCTime timeToSet(epoch);
    RTC.setTime(timeToSet);
  }

  setHrGoal = (req.indexOf("hrGoal=yes") >= 0);
  setPaceGoal = (req.indexOf("paceGoal=yes") >= 0);

  if (req.indexOf("useGPS=yes") == -1) useGPS = false;
  if (req.indexOf("useBreath=yes") == -1) useBreathing = false;

  hrLow = getParam(req, "hrL=").toInt();
  hrHigh = getParam(req, "hrH=").toInt();
  goalPaceMin = getParam(req, "pM=").toInt();
  goalPaceSec = getParam(req, "pS=").toInt();
  stepThreshold = getParam(req, "stepT=").toFloat();

  float tempMinS = getParam(req, "minS=").toFloat();
  if (tempMinS > 0.0f) minSpeedThreshold = tempMinS;

  lcdFreqMs = getParam(req, "lcdF=").toInt() * 1000;

  float pointsPerSec = getParam(req, "logR=").toFloat();
  if (pointsPerSec > 10.0f) pointsPerSec = 10.0f;
  if (pointsPerSec < 0.1f)  pointsPerSec = 0.1f;
  logFreqMs = (int)(1000.0f / pointsPerSec);
}

String getParam(String req, String tag) {
  int i = req.indexOf(tag);
  if (i == -1) return "0";
  int end = req.indexOf("&", i);
  if (end == -1) end = req.indexOf(" ", i);
  return req.substring(i + tag.length(), end);
}

void sendSetupPage(WiFiClient c) {
  c.println("HTTP/1.1 200 OK\nContent-type:text/html\n");
  c.println("<!DOCTYPE HTML><html><head><meta name='viewport' content='width=device-width, initial-scale=1'>");
  c.println("<style>body{font-family:sans-serif;background:#f2f2f7;padding:20px;text-align:center;}");
  c.println(".card{background:white;padding:15px;border-radius:12px;margin-bottom:15px;text-align:left;box-shadow:0 2px 5px rgba(0,0,0,0.1);}");
  c.println("input,select{width:100%;padding:10px;margin-top:5px;border:1px solid #ccc;border-radius:8px;}");
  c.println(".row{display:flex;gap:10px;} .col{flex:1;}");
  c.println("input[type=submit]{background:#007AFF;color:white;font-weight:bold;border:none;cursor:pointer;}");
  c.println("</style></head><body>");

  c.println("<h2>Vest Setup</h2>");

  c.println("<script>");
  c.println("function togglePace() {");
  c.println("  var gps = document.getElementById('gpsCheck');");
  c.println("  var pace = document.getElementById('paceCheck');");
  c.println("  if(!gps.checked) { pace.checked = false; pace.disabled = true; }");
  c.println("  else { pace.disabled = false; }");
  c.println("}");
  c.println("function sendData() {");
  c.println("  var now = new Date();");
  c.println("  var utc = Math.floor(now.getTime()/1000);");
  c.println("  var off = now.getTimezoneOffset() * 60;");
  c.println("  var local = utc - off;");
  c.println("  document.getElementById('tField').value = local;");
  c.println("  document.forms[0].submit();");
  c.println("}");
  c.println("</script>");

  c.println("<form action='/START' onsubmit='event.preventDefault(); sendData();'>");
  c.println("<input type='hidden' name='time' id='tField'>");

  c.println("<div class='card'><h3>Sensor Settings</h3>");
  c.println("<label><input type='checkbox' id='gpsCheck' name='useGPS' value='yes' checked onclick='togglePace()'> Enable GPS</label><br>");
  c.println("<label><input type='checkbox' name='useBreath' value='yes' checked> Track Breathing</label><br><br>");
  c.println("<label>Step Threshold (G-Force)</label><input type='number' name='stepT' value='11' step='0.1'>");
  c.println("<br><br><label>Min Speed Threshold (m/s)</label>");
  c.println("<input type='number' name='minS' value='0.8' step='0.1'>");
  c.println("<br><br><label>Data Points per Second</label>");
  c.println("<input type='number' name='logR' value='1' step='0.1' max='10'>");
  c.println("<small style='color:red'>Max: 10</small>");
  c.println("</div>");

  c.println("<div class='card'><h3>Goals</h3>");
  c.println("<label><input type='checkbox' name='hrGoal' value='yes' checked> HR Goal (Range)</label>");
  c.println("<div class='row'><div class='col'><label>Low</label><input type='number' name='hrL' value='60'></div>");
  c.println("<div class='col'><label>High</label><input type='number' name='hrH' value='100'></div></div>");
  c.println("<br><label><input type='checkbox' id='paceCheck' name='paceGoal' value='yes' checked> Pace Goal (Min/Mile)</label>");
  c.println("<div class='row'><div class='col'><label>Min</label><input type='number' name='pM' value='8'></div>");
  c.println("<div class='col'><label>Sec</label><input type='number' name='pS' value='30'></div></div></div>");

  c.println("<div class='card'><h3>Display Settings</h3>");
  c.println("<div class='row'><div class='col'><label>Screen Refresh (s)</label><input type='number' name='lcdF' value='2'></div>");
  c.println("</div></div>");

  c.println("<input type='submit' value='START WORKOUT'>");
  c.println("</form></body></html>");
}

void sendSuccessPage(WiFiClient c) {
  c.println("HTTP/1.1 200 OK\nContent-type:text/html\n");
  c.println("<body><h1>Ready!</h1><p>Starting...</p></body>");
}

// ================================================================
// DISPLAY
// ================================================================
void drawDashboardLayout() {
  tft.fillScreen(ST77XX_BLACK);
  tft.drawFastHLine(0, 100, 320, ST77XX_DARKGREY);
  tft.drawFastHLine(0, 170, 320, ST77XX_DARKGREY);
  tft.drawFastVLine(160, 0, 170, ST77XX_DARKGREY);

  tft.setTextSize(1);
  tft.setTextColor(ST77XX_WHITE);
  tft.setCursor(10, 10);  tft.print("HR");
  tft.setCursor(170, 10); tft.print("PACE");
  tft.setCursor(10, 105); tft.print("SPEED (m/s)");
  tft.setCursor(170, 105); tft.print("BREATHS");
  tft.setCursor(250, 105); tft.print("STEPS");
}

void updateDashboard() {
  // HR
  tft.setTextSize(4);
  tft.fillRect(10, 25, 100, 35, ST77XX_BLACK);
  tft.setCursor(10, 25);
  tft.setTextColor(ST77XX_RED, ST77XX_BLACK);
  if (polarConnected) {
    tft.print(currentHR);
  } else {
    tft.setTextSize(3); tft.print("???");
  }

  tft.setTextSize(1); tft.setTextColor(ST77XX_ORANGE, ST77XX_BLACK);
  tft.setCursor(10, 65);
  tft.print("(Goal: "); tft.print(hrLow); tft.print("-"); tft.print(hrHigh); tft.print(")");

  // Pace
  tft.fillRect(170, 25, 140, 35, ST77XX_BLACK);
  tft.setTextSize(4);
  tft.setCursor(170, 25); tft.setTextColor(ST77XX_YELLOW, ST77XX_BLACK);

  if (useGPS) {
    if (displayPaceMin > 0) {
      tft.print(displayPaceMin); tft.print(":");
      if (displayPaceSec < 10) tft.print("0");
      tft.print(displayPaceSec);
    } else {
      tft.setTextSize(3); tft.print("--:--");
    }
  } else {
    tft.setTextSize(3); tft.print("OFF");
  }

  if (useGPS) {
    tft.setTextSize(1); tft.setTextColor(ST77XX_ORANGE, ST77XX_BLACK);
    tft.setCursor(170, 65);
    tft.print("(Goal: <"); tft.print(goalPaceMin); tft.print(":");
    if (goalPaceSec < 10) tft.print("0");
    tft.print(goalPaceSec); tft.print(")");
  }

  // Speed (LCD shows 2 decimals)
  tft.fillRect(10, 130, 130, 25, ST77XX_BLACK);
  tft.setTextSize(2); tft.setCursor(10, 130); tft.setTextColor(ST77XX_WHITE, ST77XX_BLACK);
  if (useGPS) tft.print(displaySpeed, 2);
  else { tft.setTextSize(1); tft.print("OFF"); }

  // Breaths
  tft.fillRect(170, 130, 60, 25, ST77XX_BLACK);
  tft.setTextSize(2); tft.setCursor(170, 130); tft.setTextColor(ST77XX_BLUE, ST77XX_BLACK);
  if (useBreathing) tft.print(totalBreaths);
  else { tft.setTextSize(1); tft.print("OFF"); }

  // Steps
  tft.fillRect(250, 130, 60, 25, ST77XX_BLACK);
  tft.setTextSize(2); tft.setCursor(250, 130); tft.setTextColor(ST77XX_GREEN, ST77XX_BLACK);
  tft.print(stepCount);

  // Status row
  tft.setTextSize(2);

  tft.setCursor(10, 190);
  if (!polarConnected) {
    tft.setTextColor(ST77XX_DARKGREY, ST77XX_BLACK); tft.print("NO SIGNAL  ");
  } else {
    if (currentHR > hrHigh) { tft.setTextColor(ST77XX_RED, ST77XX_BLACK); tft.print("HR: HIGH!  "); }
    else if (currentHR < hrLow) { tft.setTextColor(ST77XX_BLUE, ST77XX_BLACK); tft.print("HR: LOW    "); }
    else { tft.setTextColor(ST77XX_GREEN, ST77XX_BLACK); tft.print("HR: GOOD   "); }
  }

  tft.setCursor(170, 190);
  if (useGPS && setPaceGoal) {
    if (displayPaceMin == 0 && displayPaceSec == 0) {
      tft.setTextColor(ST77XX_ORANGE, ST77XX_BLACK);
      tft.print("READY      ");
    } else {
      int currentSec = (displayPaceMin * 60) + displayPaceSec;
      int goalSec = (goalPaceMin * 60) + goalPaceSec;
      if (currentSec > goalSec) {
        tft.setTextColor(ST77XX_ORANGE, ST77XX_BLACK);
        tft.print("SPEED UP!  ");
      } else {
        tft.setTextColor(ST77XX_GREEN, ST77XX_BLACK);
        tft.print("ON PACE    ");
      }
    }
  } else {
    tft.setTextColor(ST77XX_DARKGREY, ST77XX_BLACK);
    tft.print("           ");
  }
}

// ================================================================
// BLE / HR / BREATHING
// ================================================================
void processPolarData() {
  const uint8_t* data = hrChar.value();
  int length = hrChar.valueLength();
  byte flags = data[0];
  int idx = 1;

  if (bitRead(flags, 0) == 0) {
    currentHR = data[idx];
    idx += 1;
  } else {
    currentHR = data[idx] | (data[idx + 1] << 8);
    idx += 2;
  }

  if (useBreathing && bitRead(flags, 4) == 1) {
    if (bitRead(flags, 3) == 1) idx += 2;
    while (idx + 1 < length) {
      uint16_t rr_raw = data[idx] | (data[idx + 1] << 8);
      idx += 2;
      float rr_ms = (rr_raw / 1024.0f) * 1000.0f;

      rrHistory[0] = rrHistory[1];
      rrHistory[1] = rrHistory[2];
      rrHistory[2] = rr_ms;

      if (rrHistory[0] > 0 && rrHistory[1] > rrHistory[0] + 5 && rrHistory[1] > rrHistory[2]) {
        totalBreaths++;
      }
    }
  }
}
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
